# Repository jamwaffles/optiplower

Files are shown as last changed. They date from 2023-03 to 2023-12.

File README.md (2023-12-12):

# Optiplower

Dell Optiplex Power supply experiments.

I want to run a Dell Optiplex 3050 Micro off an industrial 24Vdc supply. Two issues:

1. The Dell takes 19.5v
2. It will refuse to clock above 800MHz if it can't communicate with the charger to check how much
   power it can provide.

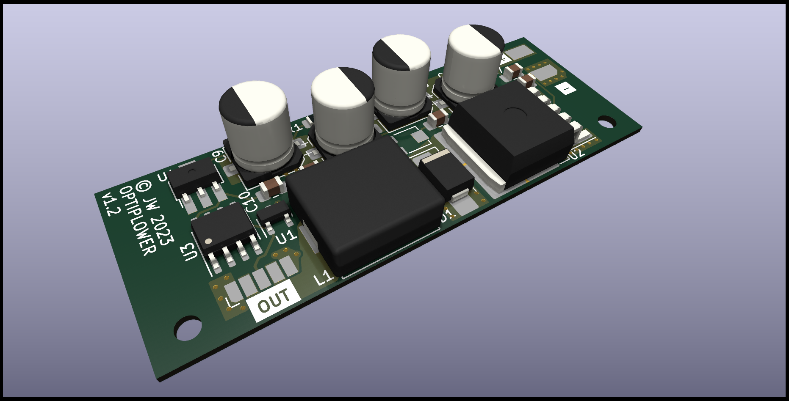
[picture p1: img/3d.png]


This project aims to solve both by incorporating:

1. A 5A DCDC converter to give 19.5v from 24v input
2. Either an ATTiny85 or a DS2502 to communicate with the mainboard and spoof it into thinking it
   has a 65W PSU attached.

Onto a single, tiny PCB that can be hidden away inside the Dell.

References:

- <https://github.com/KivApple/dell-charger-emulator>
- <https://github.com/garyStofer/DS2502_DELL_PS>
- <https://github.com/timothyjager/DellPSU>
- <https://www.instructables.com/Embedded-EEPROM-Into-DELL-Laptop-for-Charger-Ident/>
- <https://github.com/HclX/DELL_POWER_SPOOFER>
- <https://blog.project-insanity.org/2020/05/25/hardware-fix-for-dell-ac-power-adapter-could-not-be-determined/>
- Among others

Please use KiCAD 7 to open the board files. The PSU uses JLC/LCSC-sourcable parts if you'd like to
build your own.

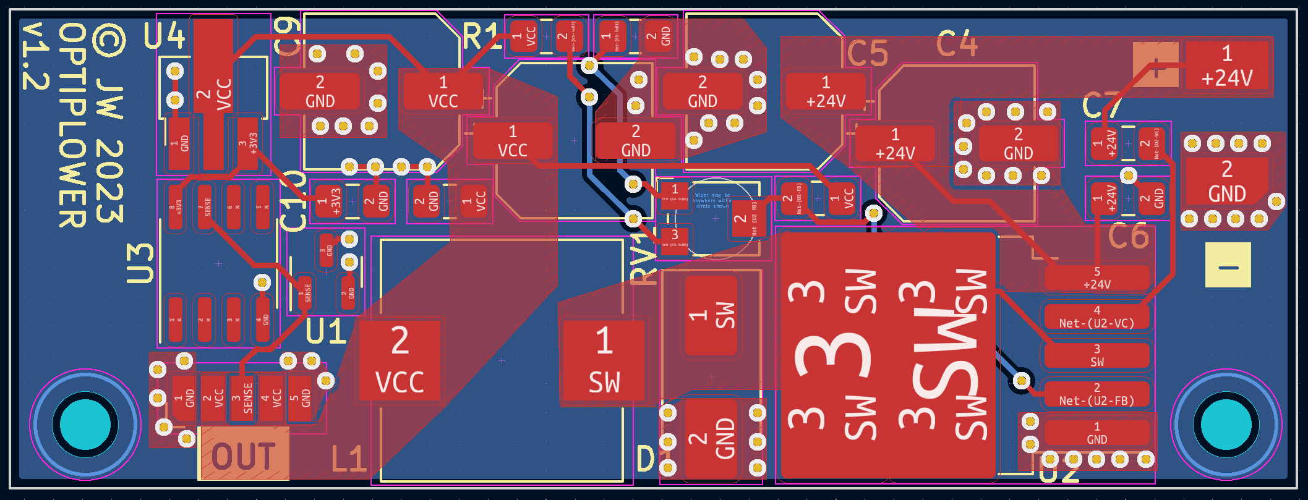
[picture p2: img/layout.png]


DigiSpark ATTiny85 devboard LED is connected to PB0

## Connection

The output connector is designed for a 5-way 1.27mm pitch ribbon cable. The 5 pins mirror the layout
of the pins on the barrel jack PCB connector.

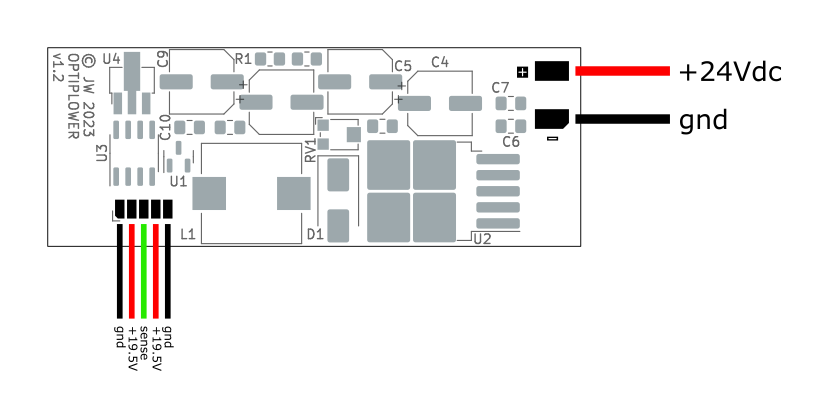
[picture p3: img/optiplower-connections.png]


## Sample dumps

- `DELL00AC090195046CN09T` (90w) from
  <https://github.com/garyStofer/DS2502_DELL_PS/blob/master/DS2502_DELL_PS.ino> or
  `DELL00AC090195046CN09T2157161543835EAL03` with checksum
- `"DELL00AC045195023CN0CDF577243865Q27F2A05=\x94"` (45w)

## Firmware setup

Uses Arduino CLI

```bash
curl -fsSL https://raw.githubusercontent.com/arduino/arduino-cli/master/install.sh | BINDIR=~/.local/bin sh
```

## Programming

You'll need to edit the `memory` variable in `ds2502-emulator/src/DS2502.h` to change how the
charger identifies.

```bash
cd ds2502-emulator

make

make program

make fuses
```

Works with ATTiny25-10SSU, but can be made to target ATTiny85, etc by modifying the `AVRDUDE_MCU?`
line in `./ds2502-emulator/Makefile` along with the `fqbn...` line in
`./ds2502-emulator/sketch.yaml`.

## Burning bootloader issues

> Don't actually need to use the bootloader - I can use the USBASP directly. This section is just
> left here as a note.

Arduino IDE 2.x, "burn bootloader" with usbasp programmer selected.

Need to swap out programmer for the one on the system or various lib versions won't match, e.g.

```
error while loading shared libraries: libtinfo.so.5: cannot open shared object file: No such file or directory
```

E.g.

```bash
mv /home/james/.arduino15/packages/arduino/tools/avrdude/6.0.1-arduino5/bin/avrdude /home/james/.arduino15/packages/arduino/tools/avrdude/6.0.1-arduino5/bin/avrdude_old
ln -s $(which avrdude) /home/james/.arduino15/packages/arduino/tools/avrdude/6.0.1-arduino5/bin/avrdude
```

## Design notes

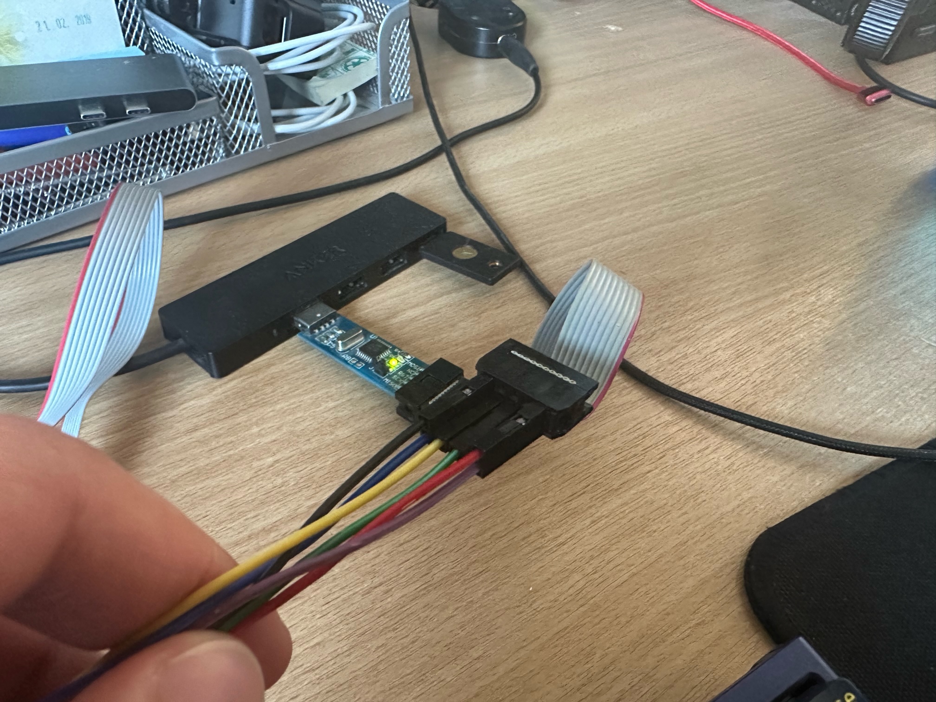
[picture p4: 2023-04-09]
img/usbasp-pinout.jpeg

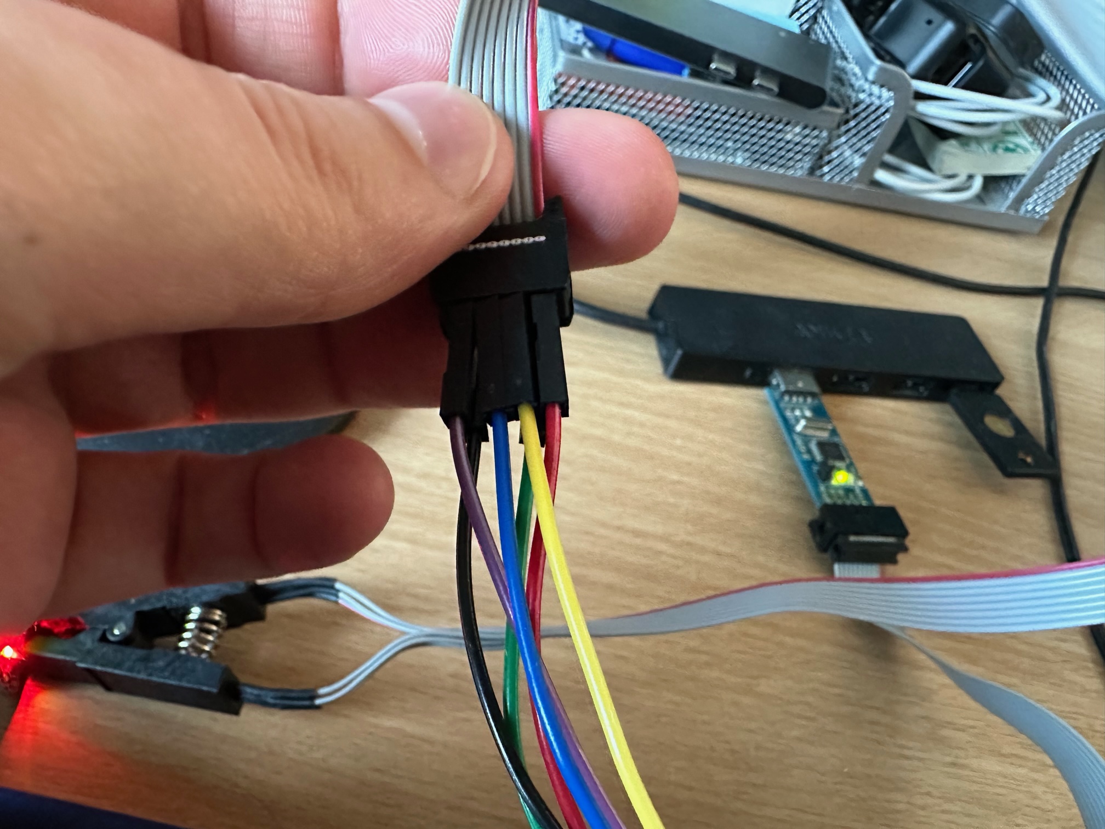
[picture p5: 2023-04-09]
img/soic-8-pinout.jpeg

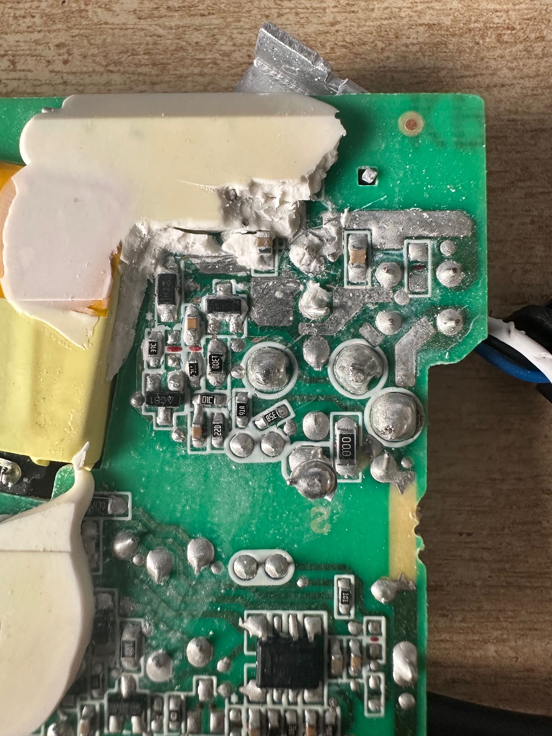
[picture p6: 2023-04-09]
img/dell-65w-pcb.jpg

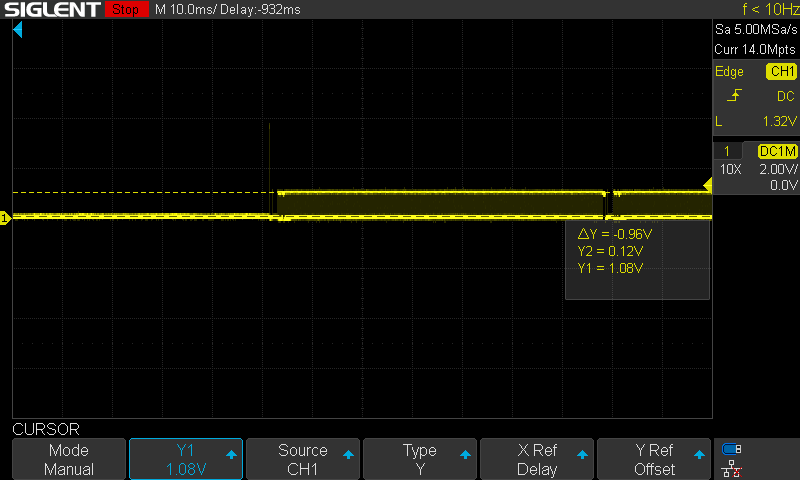
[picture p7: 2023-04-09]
img/attiny-with-pullups.png

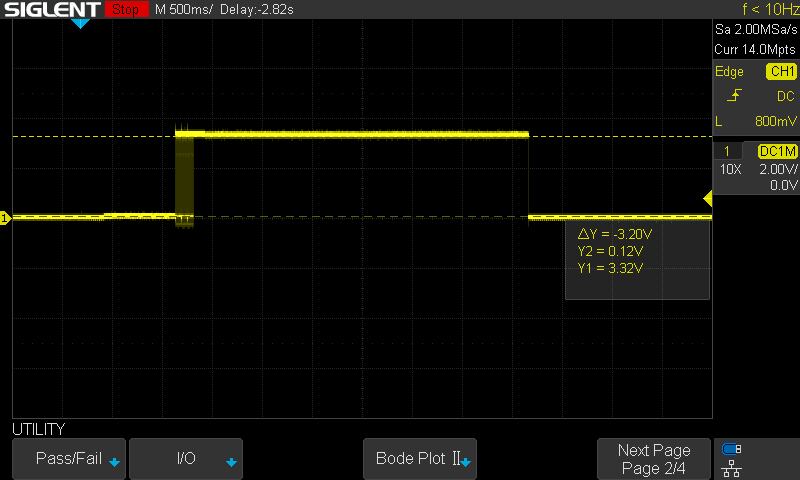
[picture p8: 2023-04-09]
img/dell-130w-plugin.png

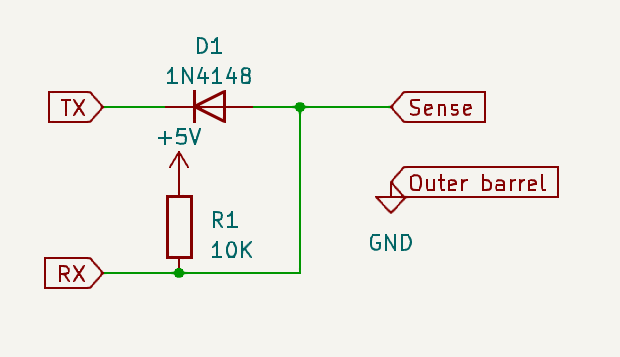
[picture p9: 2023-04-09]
img/dumper.png

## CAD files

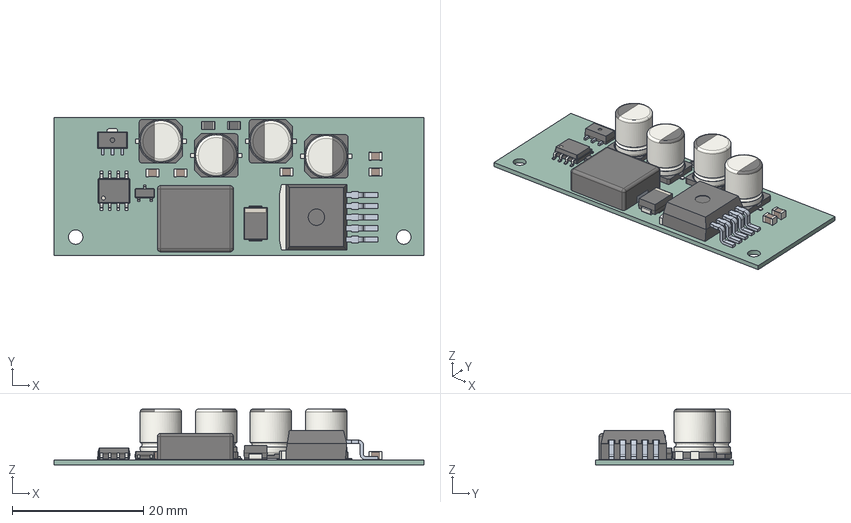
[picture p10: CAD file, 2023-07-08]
hardware/optiplower.step
56.4 x 21.0 x 8.53 mm
optiplower PCB

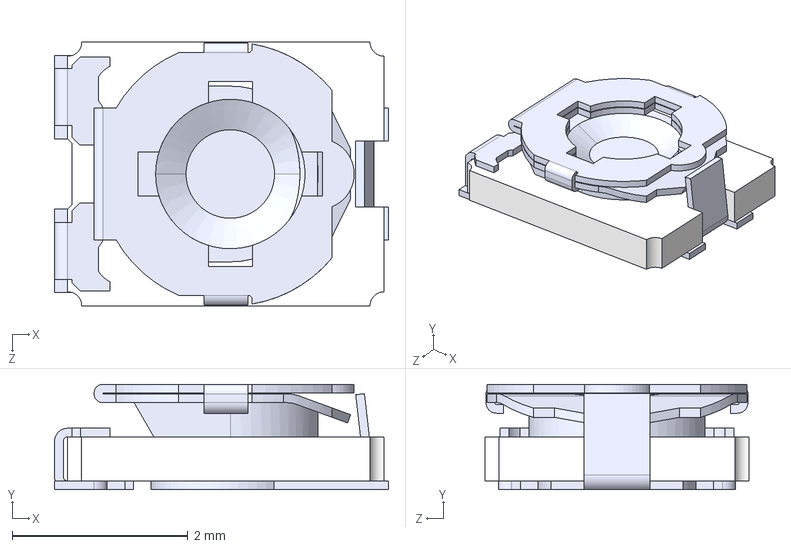
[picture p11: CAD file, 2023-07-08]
hardware/TC33X-2-102E.step
3.80 x 1.20 x 3.00 mm

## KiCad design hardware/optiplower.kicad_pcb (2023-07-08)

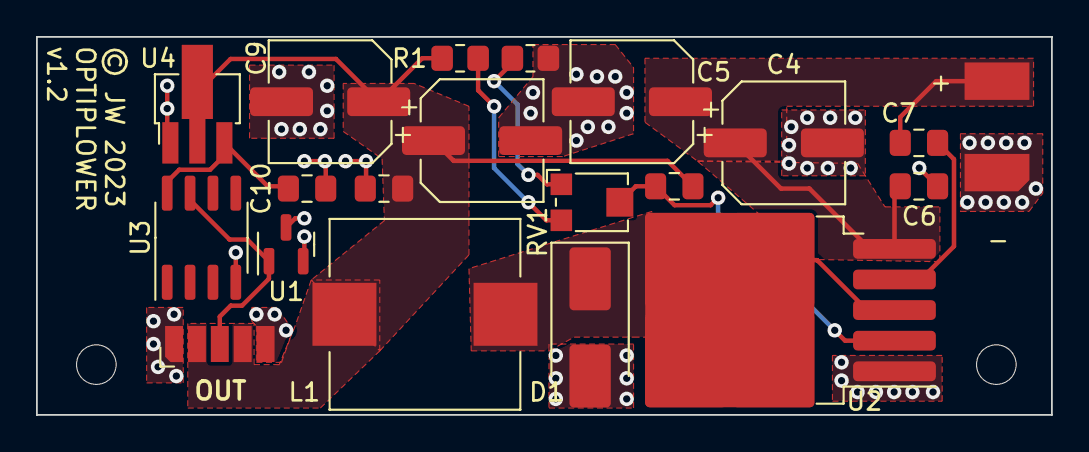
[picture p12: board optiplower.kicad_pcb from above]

Board: 2 copper layers, 56.4 x 21.0 mm, 22 parts (0 on the bottom side), 10 nets.

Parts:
C4, C5, C9, C11: 220uF; CP_Elec_6.3x7.7
C6, C7, C10, C12: 1uF; C_0805_2012Metric_Pad1.18x1.45mm_HandSolder
C8: 33n; C_0805_2012Metric_Pad1.18x1.45mm_HandSolder
D1: SK84B; D_SMB_Handsoldering
H1, H2: MountingHole_2.2mm_M2
J1: Conn_01x02; 5.08_PWR_IN
J2: Conn_01x03; Output_pads
L1: 47uH; L_MDA1050_10x11mm
R1: 150K; R_0805_2012Metric_Pad1.20x1.40mm_HandSolder
R2: 10K; R_0805_2012Metric_Pad1.20x1.40mm_HandSolder
RV1: 1K; Potentiometer_Bourns_TC33X_Vertical
U1: DS2502S+; SOT-23
U2: XL4015; TO-263-5_TabPin3
U3: ATtiny25-10SSU; SOIC-8_3.9x4.9mm_P1.27mm
U4: LR7533-M; SOT-89-3_Handsoldering

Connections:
+3V3: C10.1, U3.8 (VCC), U4.3 (VO)
+24V: C4.1, C5.1, C6.1, C7.1, J1.1, U2.5 (VIN)
/SENSE: J2.3, U1.1 (SDQ), U3.7 (PB2)
/SW: D1.1 (K), L1.1, U2.3 (SW)
GND: C4.2, C5.2, C6.2, C9.2, C10.2, C11.2, C12.2, D1.2 (A), J1.2, J2.1, J2.5, R2.2, U1.2 (VSS), U1.3 (VSS), U2.1 (GND), U3.4 (GND), U4.1 (GND)
unnamed: R1.2, RV1.3
unnamed: R2.1, RV1.1
unnamed: C8.2, RV1.2, U2.2 (FB)
unnamed: C7.2, U2.4 (VC)
VCC: C8.1, C9.1, C11.1, C12.1, J2.2, J2.4, L1.2, R1.1, U4.2 (VI)

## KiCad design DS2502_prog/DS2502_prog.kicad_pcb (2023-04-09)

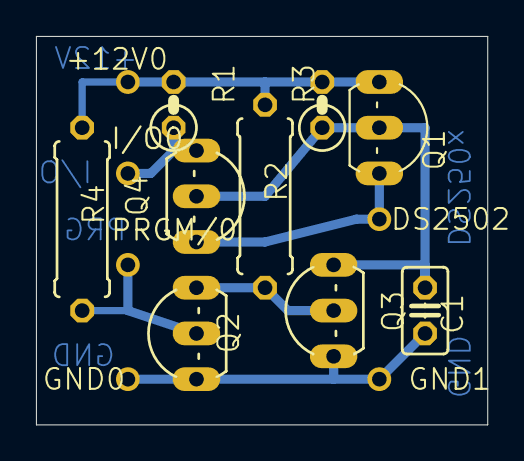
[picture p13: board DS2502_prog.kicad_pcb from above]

Board: 2 copper layers, 25.1 x 21.6 mm, 15 parts (0 on the bottom side), 7 nets.

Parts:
+12V0: SOLDER_POINTA; P1-13
C1: 470pf; C025-025X050
DS2502: SOLDER_POINTA; P1-13
GND0, GND1: SOLDER_POINTA; P1-13
I/O0: SOLDER_POINTA; P1-13
PRGM/0: SOLDER_POINTA; P1-13
Q1: VP0106N3; TO92-
Q2, Q3, Q4: 2N7000; TO92-LINE
R1: 4.7K; 0207_2V
R2: 10k; 0309_10
R3: 10K; 0207_2V
R4: 100k; 0309_10

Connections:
unnamed: +12V0.1, Q1.3, R1.2, R2.2, R3.2, R4.2
unnamed: I/O0.1, Q4.3, R1.1
unnamed: Q2.1, Q3.2, R2.1
unnamed: PRGM/0.1, Q2.2, R4.1
unnamed: C1.2, GND0.1, GND1.1, Q2.3, Q3.3
unnamed: C1.1, Q1.2, Q3.1, Q4.2, R3.1
unnamed: DS2502.1, Q1.1, Q4.1

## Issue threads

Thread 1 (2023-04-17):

Update production zip

matthewcooper, 2023-04-17:
Hello

Great solution thank you

Can you update the gerber.zip to the new SMD version. I also notice that items U3 to U6 are missing from the BOM

(I have tried to sort this out but KiCAD not a bit of software I open much)

jamwaffles, 2023-04-17:
I've just pushed the latest SMD gerbers. I've also added the ATTiny (`U3`) to the BOM, although I'm not sure what you mean when referring to `U4`, `U5` and `U6` as `U4` is definitely in the BOM, and `U5` and `U6` don't exist?

jamwaffles, 2023-04-17:
Ah, were you looking at the PCB screenshots in the README? I've just updated those to the most recent SMD version. The non-existent `U*` parts were alternative footprints as I wasn't sure what I could source at the time.

matthewcooper, 2023-04-17:
Yes, it was the old version thank you for the quick fix.

Closed 2023-04-17.

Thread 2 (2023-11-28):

input power supply requirements

jensvanhoof86, 2023-11-28:
Hi!

The project looks great and exactly what I'm looking for.
What would be the voltage and current limit for the industrial power supply at the input of the PCB?

I have a 28VDC source I'd like to use but I'm not sure if that would work?

jamwaffles, 2023-11-28:
Hey, thanks for the interest! The circuit is centered around the XL4015 which, according to its [datasheet](https://www.xlsemi.com/datasheet/XL4015-EN.pdf), has an input voltage up to 36V so I think you should be just fine with 28V input.

jamwaffles, 2023-12-12:
Closing as resolved,

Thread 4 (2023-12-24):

pin swap in documentation (power out)

jensvanhoof86, 2023-12-24:
Hi,

The connection diagram (white background image) for the output  connector is not correct. On your drawing the outer connections are marked as +19.5V, followed by GND and SENSE in the middle.

It seems however that GND is on the outside, then followed by +19.5V. It is correctly displayed in the board screenshot where the net names are displayed. There it is clear that GND is pin 1 and 5, rather than 2 and 4.

jamwaffles, 2023-12-24:
Agh I'm really sorry about that. Just pushed a fix to master! Thanks for pointing it out.

Closed 2023-12-24.

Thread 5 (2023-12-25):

programming the Attiny25, wiring

jensvanhoof86, 2023-12-25:
Question, how did you connect your USBASP to your PCB? Did you just solder 6 wires to the leads of the SMD chip or did you program it before soldering it to the board?

jamwaffles, 2023-12-26:
I used a programming clip like this:

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

Search eBay for "soic clip" and you should find something similar.

jensvanhoof86, 2023-12-27:
thanks a lot! I've just ordered one.

jamwaffles, 2023-12-27:
Great! I'll close this issue as resolved then :)

Closed 2023-12-27.

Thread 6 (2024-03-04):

DS2502 sense

jensvanhoof86, 2024-03-04:
Hi,

I have just programmed a DS2502 with the following code "DELL00AC090195046CN09T" using Gary Stofer's programmer sketch. I have had no luck with the Attiny chips so far so I figured I'd give the actual DS2502 a shot.

I have the DS2502 currently on a breadboard with GND connected from the optiplower to the chip, and the datapin of my 'dell' barrel connector connected to the data pin of the DS2502. Unfortunately, no luck.

Looking with a logic analyzer, I see the following with an original Dell adapter:

-as long as the barrel connector is not in the computer, sense line is low
-when the connector goes in the computer, the sense line is pulled high and the data communication is initiated next. After the data exchange, the sense line idles back high.

However, with my setup, the sense line is noisy even before I plug the barrel connector in so the data is obviously not exchanged correctly and it doesn't work.

Any ideas what I could be missing? Another external pull-up/down resistor required?

jamwaffles, 2024-03-04:
I'm afraid it's been a while since I worked on this project last so my memory is fuzzy, but I think you might need a ~10k pullup. I didn't write any of the code in this repo, just hacked it up for ATTiny, but you might want to look through it to see if there is an internal pull up/down enabled anywhere.

I also vaguely remember having to connect the NC (Not Connected :roll_eyes:) pin on the DS2502 to get it to work, but I could be wrong there...

jensvanhoof86, 2024-03-04:
In the programmer there's a 4.7k pullup, but in theory I'd expect that pull-up on the 'master' side, so within the PC.
I did see in your schematic that you have the NC pin connected to GND. I'll try to investigate further. Thanks!

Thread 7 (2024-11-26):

It doesn't work at all.

Foltifeki, 2024-11-26:
For some reason it doesn't work, the code doesn't run with all sorts of errors
and how exactly should I flash the code to the chip?
this attiny 85 chip can be connected to the computer via usb
it was recognized by arduino here a long time ago
now I can barely find a link from which I can insert it into the board manager
but now it doesn't recognize it
the code doesn't work
it just gives errors everywhere
what can be done in such a case?

jamwaffles, 2024-11-28:
Did you look at [firmware setup](https://github.com/jamwaffles/optiplower?tab=readme-ov-file#firmware-setup) and [programming](https://github.com/jamwaffles/optiplower?tab=readme-ov-file#programming) in the readme? I used a programming clip [like this one](https://github.com/jamwaffles/optiplower/issues/5#issuecomment-1869703161) to program the ATTiny.

You need to give me more information than "the code doesn't work" and "it just gives errors everywhere". At a minimum, paste the errors here along with the commands you used.

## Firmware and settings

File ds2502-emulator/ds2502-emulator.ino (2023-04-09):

/*
 *    Example-Code that emulates a DS2502 - 1kbit EEPROM as a dell power supply
 *
 *    Tested with
 *    - dell notebook https://forum.pjrc.com/threads/33640-Teensy-2-OneWire-Slave
 *    - DS9490R-Master, atmega328@16MHz as Slave
 *    - Arduino ProMini clone
 *    - esp8266 (ESP-01 module, using GPIO2 with a 10k pull-up resistor)
 *    - Dell Inspiron 15R N5110 and Dell Inspiron 15R 5521 @130W
 *
 *    OneWire messaging starts when AC adapter is plugged to notebook,
 *    try to use parasite powering but unfortunately it doesn't provide enough power,
 *    so You need DC-DC converter to power MCU
 *    Linear regulators can only be used as a temporary replacement, e.g., a combination of LM7805 and AMS1117.
 *    During the test, the temperature of the LM7805 reaches 60 celsius when powering an ESP-01 module.
 *
 *    thanks to Nik / ploys for supplying traces of real data-traffic to figure out communication:
 *    - reset and presence detection normal
 *    - cmd from master: 0xCC -> skip rom, so there is only ONE device allowed on the bus
 *    - cmd from master: 0xF0 -> read memory
 *    - address request from master: 0x0008
 *    - master listens for data, gets CRC of seconds cmd and address first, then listens for 3 bytes, does not listen any further
 *    !!! Note that some latest Dell models may ask for more information !!!
 */

// Local, gutted library in an attempt to make it work on ATTiny25
#include "src/OneWireHub.h"
#include "src/DS2502.h"

// Full library which works on 85/45 but not 25
// #include "OneWireHub.h"
// #include "DS2502.h"

// Using GPIO2 on an ESP01 module (Requires 10k pull-up to 3.3V)
constexpr uint8_t pin_onewire{2};

// // EEPROM strings, the length is always 42 bytes, including 2 bytes of CRC16 checksum.
// constexpr uint8_t chargerStrlen{42};
// // // https://github.com/KivApple/dell-charger-emulator
// // constexpr const char* charger45W = "DELL00AC045195023CN0CDF577243865Q27F2A05\x3D\x94";
// // https://nickschicht.wordpress.com/2009/07/15/dell-power-supply-fault/
// constexpr const char *charger65W = "DELL00AC065195033CN05U0927161552F31B8A03\xBC\x8F";
// // constexpr const char* charger90W = "DELL00AC090195046CN0C80234866161R23H8A03\x4D\x7C";
// // I made this up, works with Dell Inspiron 15R N5110 and Dell Inspiron 15R 5521
// // constexpr const char* charger130W = "DELL00AC130195067CN0CDF577243865Q27F2233\x9D\x72";

auto hub = OneWireHub(pin_onewire);
auto dellCH = DS2502(0x28, 0x0D, 0x01, 0x08, 0x0B, 0x02, 0x0A); // address does not matter, laptop uses skipRom -> note that therefore only one slave device is allowed on the bus

void setup()
{
    // Serial.begin(115200);
    // Serial.println("OneWire-Hub DS2502 aka Dell Charger");

    // Setup OneWire
    hub.attach(dellCH);
    // Populate the emulated EEPROM with the 42 byte ID string
    // dellCH.writeMemory((uint8_t *)charger65W, chargerStrlen);
}

void loop()
{
    // following function must be called periodically
    hub.poll();
}

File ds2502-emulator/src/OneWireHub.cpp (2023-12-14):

#include "OneWireHub.h"
#include "OneWireItem.h"

#include "platform.h"

OneWireHub::OneWireHub(const uint8_t pin)
{
    _error = Error::NO_ERROR;

    slave_list = nullptr;

    // prepare pin
    pin_bitMask = PIN_TO_BITMASK(pin);
    pin_baseReg = PIN_TO_BASEREG(pin);
    pinMode(pin, INPUT); // first port-access should by done by this FN, does more than DIRECT_MODE_....
    DIRECT_WRITE_LOW(pin_baseReg, pin_bitMask);

    static_assert(VALUE_IPL, "Your architecture has not been calibrated yet, please run examples/debug/calibrate_by_bus_timing and report instructions per loop (IPL) to https://github.com/orgua/OneWireHub");
    static_assert(ONEWIRE_TIME_VALUE_MIN > 2, "YOUR ARCHITECTURE IS TOO SLOW, THIS MAY RESULT IN TIMING-PROBLEMS"); // it could work though, never tested
}

// attach a sensor to the hub
void OneWireHub::attach(OneWireItem &sensor)
{
    slave_list = &sensor;
}

bool OneWireHub::detach(const OneWireItem &sensor)
{
    return 0;
}

bool OneWireHub::detach(const uint8_t slave_number)
{
    //
}

bool OneWireHub::poll(void)
{
    _error = Error::NO_ERROR;

    while (true)
    {
        // // this additional check prevents an infinite loop when calling this FN without sensors attached
        // if (slave_count == 0)
        //     return true;

        // Once reset is done, go to next step
        if (checkReset())
            return false;

        // Reset is complete, tell the master we are present
        if (showPresence())
            return false;

        // Now that the master should know we are here, we will get a command from the master
        if (recvAndProcessCmd())
            return false;

        // on total success we want to start again, because the next reset could only be ~125 us away
    }
}

bool OneWireHub::checkReset(void) // there is a specific high-time needed before a reset may occur -->  >120us
{
    static_assert(ONEWIRE_TIME_RESET_MIN[0] > (ONEWIRE_TIME_SLOT_MAX[0] + ONEWIRE_TIME_READ_MAX[0]), "Timings are wrong"); // last number should read: max(ONEWIRE_TIME_WRITE_ZERO,ONEWIRE_TIME_READ_MAX)
    static_assert(ONEWIRE_TIME_READ_MAX[0] > ONEWIRE_TIME_WRITE_ZERO[0], "switch ONEWIRE_TIME_WRITE_ZERO with ONEWIRE_TIME_READ_MAX in checkReset(), because it is bigger (worst case)");
    static_assert(ONEWIRE_TIME_RESET_MAX[0] > ONEWIRE_TIME_RESET_MIN[0], "Timings are wrong");
#if OVERDRIVE_ENABLE
    static_assert(ONEWIRE_TIME_RESET_MIN[1] > (ONEWIRE_TIME_SLOT_MAX[1] + ONEWIRE_TIME_READ_MAX[1]), "Timings are wrong");
    static_assert(ONEWIRE_TIME_READ_MAX[1] > ONEWIRE_TIME_WRITE_ZERO[1], "switch ONEWIRE_TIME_WRITE_ZERO with ONEWIRE_TIME_READ_MAX in checkReset(), because it is bigger (worst case)");
    static_assert(ONEWIRE_TIME_RESET_MAX[0] > ONEWIRE_TIME_RESET_MIN[1], "Timings are wrong");
#endif

    DIRECT_MODE_INPUT(pin_baseReg, pin_bitMask);

    // is entered if there are two resets within a given time (timeslot-detection can issue this skip)
    if (_error == Error::RESET_IN_PROGRESS)
    {
        _error = Error::NO_ERROR;
        if (waitLoopsWhilePinIs(ONEWIRE_TIME_RESET_MIN[od_mode] - ONEWIRE_TIME_SLOT_MAX[od_mode] - ONEWIRE_TIME_READ_MAX[od_mode], false) == 0) // last number should read: max(ONEWIRE_TIME_WRITE_ZERO,ONEWIRE_TIME_READ_MAX)
        {
#if OVERDRIVE_ENABLE
            const timeOW_t loops_remaining = waitLoopsWhilePinIs(ONEWIRE_TIME_RESET_MAX[0], false); // showPresence() wants to start at high, so wait for it
            if (od_mode && ((ONEWIRE_TIME_RESET_MAX[0] - ONEWIRE_TIME_RESET_MIN[od_mode]) > loops_remaining))
            {
                od_mode = false; // normal reset detected, so leave OD-Mode
            };
#else
            waitLoopsWhilePinIs(ONEWIRE_TIME_RESET_MAX[0], false); // showPresence() wants to start at high, so wait for it
#endif
            return false;
        }
    }

    if (!DIRECT_READ(pin_baseReg, pin_bitMask))
        return true; // just leave if pin is Low, don't bother to wait, TODO: really needed?

    // wait for the bus to become low (master-controlled), since we are polling we don't know for how long it was zero
    if (waitLoopsWhilePinIs(ONEWIRE_TIME_RESET_TIMEOUT, true) == 0)
    {
        //_error = Error::WAIT_RESET_TIMEOUT;
        return true;
    }

    const timeOW_t loops_remaining = waitLoopsWhilePinIs(ONEWIRE_TIME_RESET_MAX[0], false);

    // wait for bus-release by master
    if (loops_remaining == 0)
    {
        _error = Error::VERY_LONG_RESET;
        return true;
    }

#if OVERDRIVE_ENABLE
    if (od_mode && ((ONEWIRE_TIME_RESET_MAX[0] - ONEWIRE_TIME_RESET_MIN[0]) > loops_remaining))
    {
        od_mode = false; // normal reset detected, so leave OD-Mode
    };
#endif

    // If the master pulled low for to short this will trigger an error
    // if (loops_remaining > (ONEWIRE_TIME_RESET_MAX[0] - ONEWIRE_TIME_RESET_MIN[od_mode])) _error = Error::VERY_SHORT_RESET; // could be activated again, like the error above, errorhandling is mature enough now

    return (loops_remaining > (ONEWIRE_TIME_RESET_MAX[0] - ONEWIRE_TIME_RESET_MIN[od_mode]));
}

bool OneWireHub::showPresence(void)
{
    static_assert(ONEWIRE_TIME_PRESENCE_MAX[0] > ONEWIRE_TIME_PRESENCE_MIN[0], "Timings are wrong");
#if OVERDRIVE_ENABLE
    static_assert(ONEWIRE_TIME_PRESENCE_MAX[1] > ONEWIRE_TIME_PRESENCE_MIN[1], "Timings are wrong");
#endif

    // Master will delay it's "Presence" check (bus-read)  after the reset
    waitLoopsWhilePinIs(ONEWIRE_TIME_PRESENCE_TIMEOUT, true); // no pinCheck demanded, but this additional check can cut waitTime

    // pull the bus low and hold it some time
    DIRECT_WRITE_LOW(pin_baseReg, pin_bitMask);
    DIRECT_MODE_OUTPUT(pin_baseReg, pin_bitMask); // drive output low

    wait(ONEWIRE_TIME_PRESENCE_MIN[od_mode]); // stays till the end, because it drives the bus low itself

    DIRECT_MODE_INPUT(pin_baseReg, pin_bitMask); // allow it to float

    // When the master or other slaves release the bus within a given time everything is fine
    if (waitLoopsWhilePinIs((ONEWIRE_TIME_PRESENCE_MAX[od_mode] - ONEWIRE_TIME_PRESENCE_MIN[od_mode]), false) == 0)
    {
        _error = Error::PRESENCE_LOW_ON_LINE;
        return true;
    }

    return false;
}

bool OneWireHub::recvAndProcessCmd(void)
{
    uint8_t address[8], cmd;
    bool flag = false;

    recv(&cmd);

    if (_error == Error::RESET_IN_PROGRESS)
        return false; // stay in poll()-loop and trigger another datastream-detection
    if (_error != Error::NO_ERROR)
        return true;

    switch (cmd)
    {
    case 0xCC: // SKIP ROM
        slave_list->duty(this);
        break;

    default: // Unknown command

        _error = Error::INCORRECT_ONEWIRE_CMD;
    }

    if (_error == Error::RESET_IN_PROGRESS)
        return false;

    return (_error != Error::NO_ERROR);
}
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

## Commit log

2023-03-24 Schematic, most footprints
    [optiplower.kicad_pcb, optiplower.kicad_sch]
2023-03-24 V3 with upside down regulator
    [optiplower.kicad_pcb, optiplower.kicad_sch]
2023-03-24 Add LMR14050 part
    [optiplower.kicad_sch]
2023-03-24 Use JLC basic parts for some things
    [optiplower.kicad_sch]
2023-03-24 Production files
    [optiplower.kicad_pcb, optiplower.kicad_sch]
2023-03-27 Fix ATTiny part numbers for footprint
    [optiplower.kicad_pcb, optiplower.kicad_sch]
2023-03-27 Firmware and dumps to spoof charger
2023-03-27 Notes and images and stuff
    [dumper.kicad_sch]
2023-03-28 Disable pullups to increase drive voltage
2023-03-28 Add hex dump from cannibalised Dell 65w charger
2023-03-28 PCB shots of Dell 65W charger
2023-03-28 Add half done programmer board
    [DS2502_prog.kicad_pcb, DS2502_prog.kicad_sch]
2023-03-29 WIP programmer design restart
    [Programmer.kicad_pcb, Programmer.kicad_sch]
2023-03-29 Correct ATTiny PN
    [optiplower.kicad_sch]
2023-03-29 LCSC parts
    [Programmer.kicad_sch]
2023-03-29 Calibrate crappy ATTiny clock
2023-03-29 More oscillator calibration
2023-03-29 Messing around trying to get timings right in PulseView
    [optiplower.kicad_sch]
2023-03-30 Arduino notes
2023-03-30 65W charger trace
2023-03-30 Arduino FW using OneWireHub
2023-03-30 Move PCB into hardware/ folder
    [dumper.kicad_sch, optiplower.kicad_pcb, optiplower.kicad_sch]
2023-03-30 Works with Arduino!
2023-03-30 Remove unused devices
2023-03-30 Arduino CLI build
2023-03-30 Remove Serial.println, run format
2023-03-30 Remove some error handling
    [OneWireHub.cpp]
2023-04-09 Fix 3.3v regulator pinout
    [optiplower.kicad_pcb, optiplower.kicad_sch]
2023-04-09 Update part details
    [optiplower.kicad_pcb]
2023-04-09 Make design completely SMD
    [optiplower.kicad_pcb, optiplower.kicad_sch]
2023-04-17 Update gerbers for latest SMD spin
2023-04-17 Add ATTiny to BOM
    [optiplower.kicad_pcb, optiplower.kicad_sch]
2023-06-20 PCB thickness to 0.8mm
    [optiplower.kicad_pcb]
2023-07-03 Convert everything to STEP so export works
    [optiplower.kicad_pcb]
2023-07-08 Relayout so caps fit in gap
    [TC33X-2-102E.step, optiplower.kicad_pcb, optiplower.kicad_sch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]
2023-07-08 v1.1 sent to fab
    [optiplower.kicad_pcb, optiplower.step]

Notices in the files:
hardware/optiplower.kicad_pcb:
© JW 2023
